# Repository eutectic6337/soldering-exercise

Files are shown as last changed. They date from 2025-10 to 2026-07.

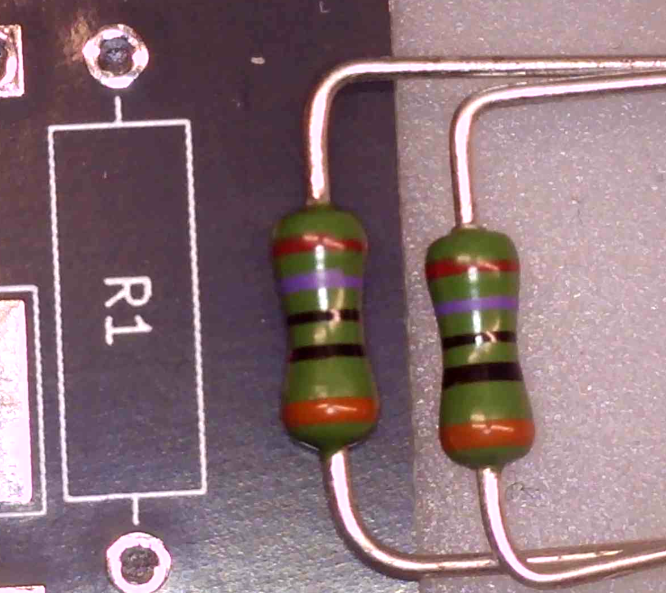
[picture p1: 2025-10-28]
i/THT resistor bend.png

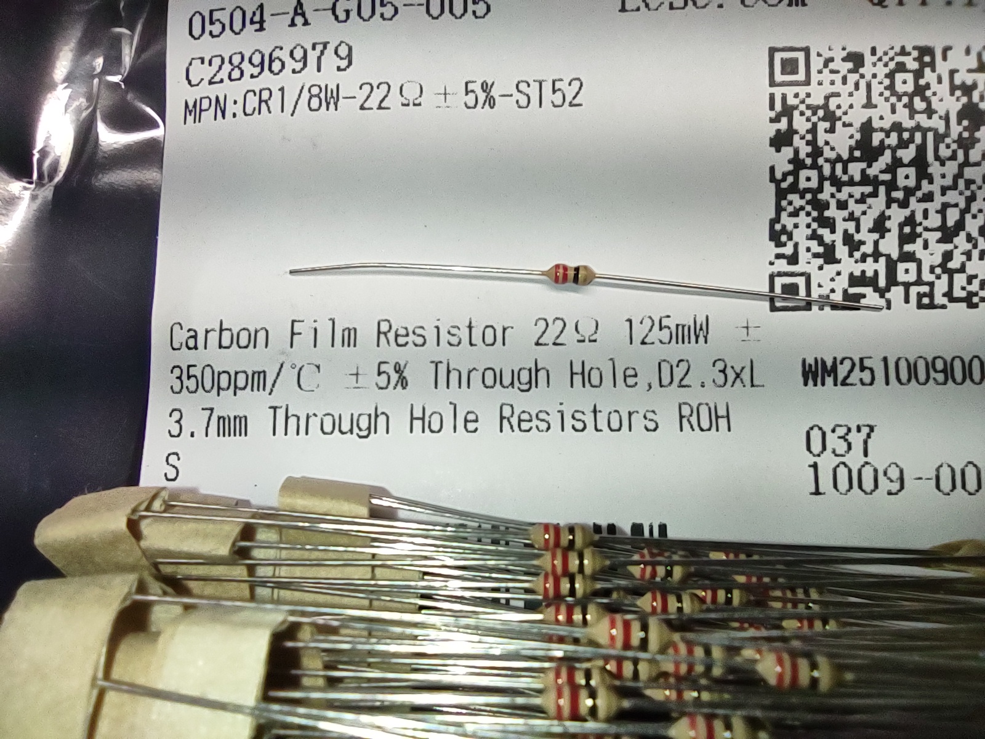
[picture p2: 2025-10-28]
i/THT resistor 22R.jpg

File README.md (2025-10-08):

# soldering-exercise
provide practice for novice solderers with several levels of difficulty

a single board with 2 alternative circuits:

- SAO connector/battery holder, 2 LEDs + 2 resistors

- trickier: SAO connector/battery holder, 555 timer + 2 capacitors + 4 resistors + 2 LEDs

with through-hole and surface-mount pads for each component

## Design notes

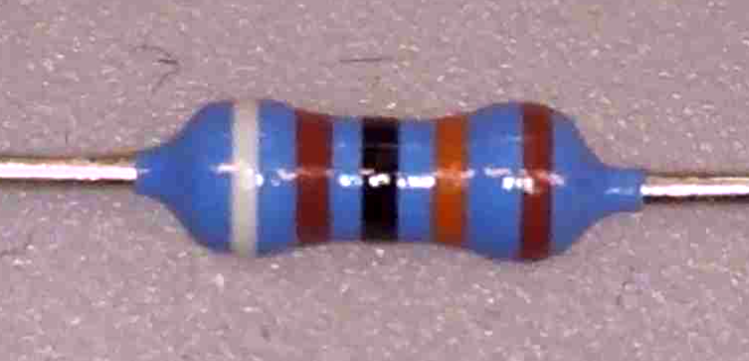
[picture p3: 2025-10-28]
i/THT resistor 910K.png

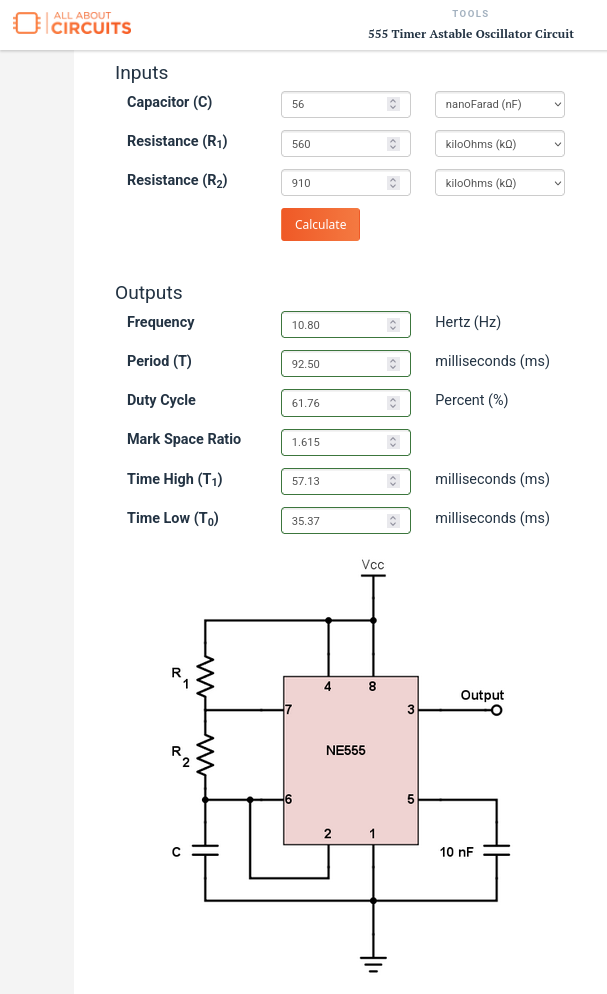
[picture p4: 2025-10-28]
i/Screenshot_555-astable.png

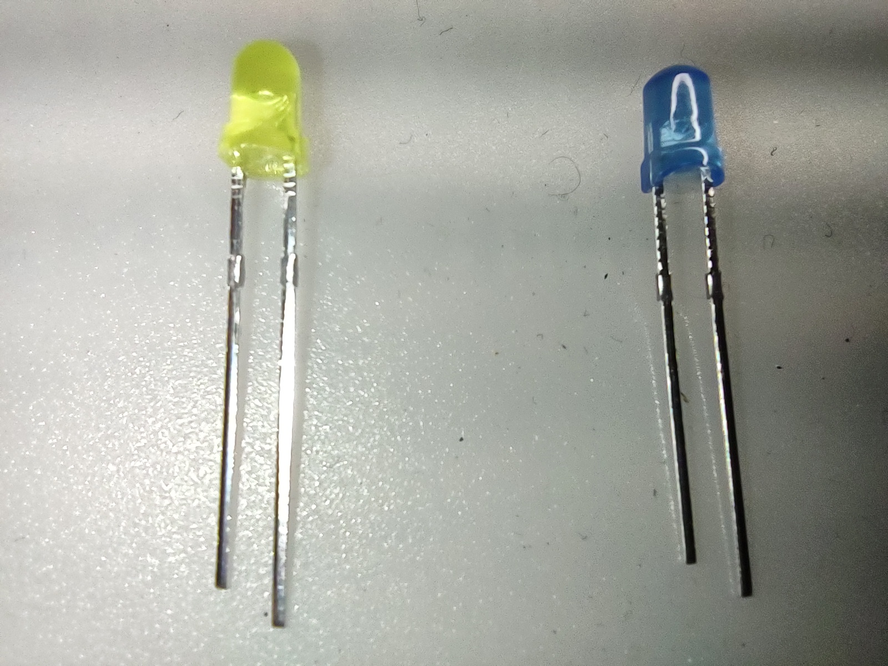
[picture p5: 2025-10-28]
i/THT LED yellow.jpg

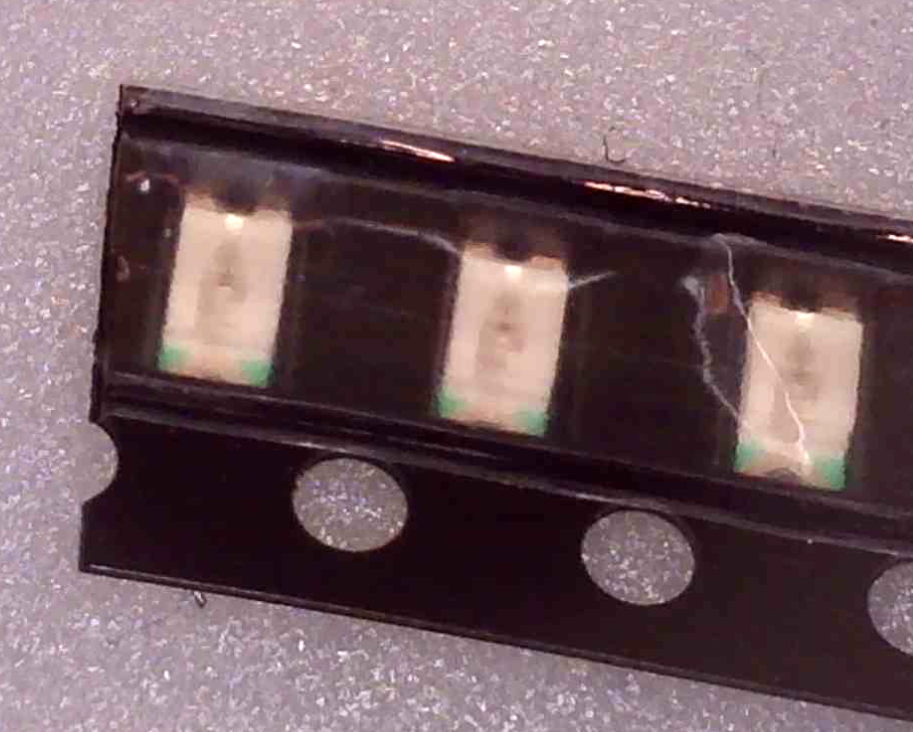
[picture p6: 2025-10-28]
i/SMD LED tape.png

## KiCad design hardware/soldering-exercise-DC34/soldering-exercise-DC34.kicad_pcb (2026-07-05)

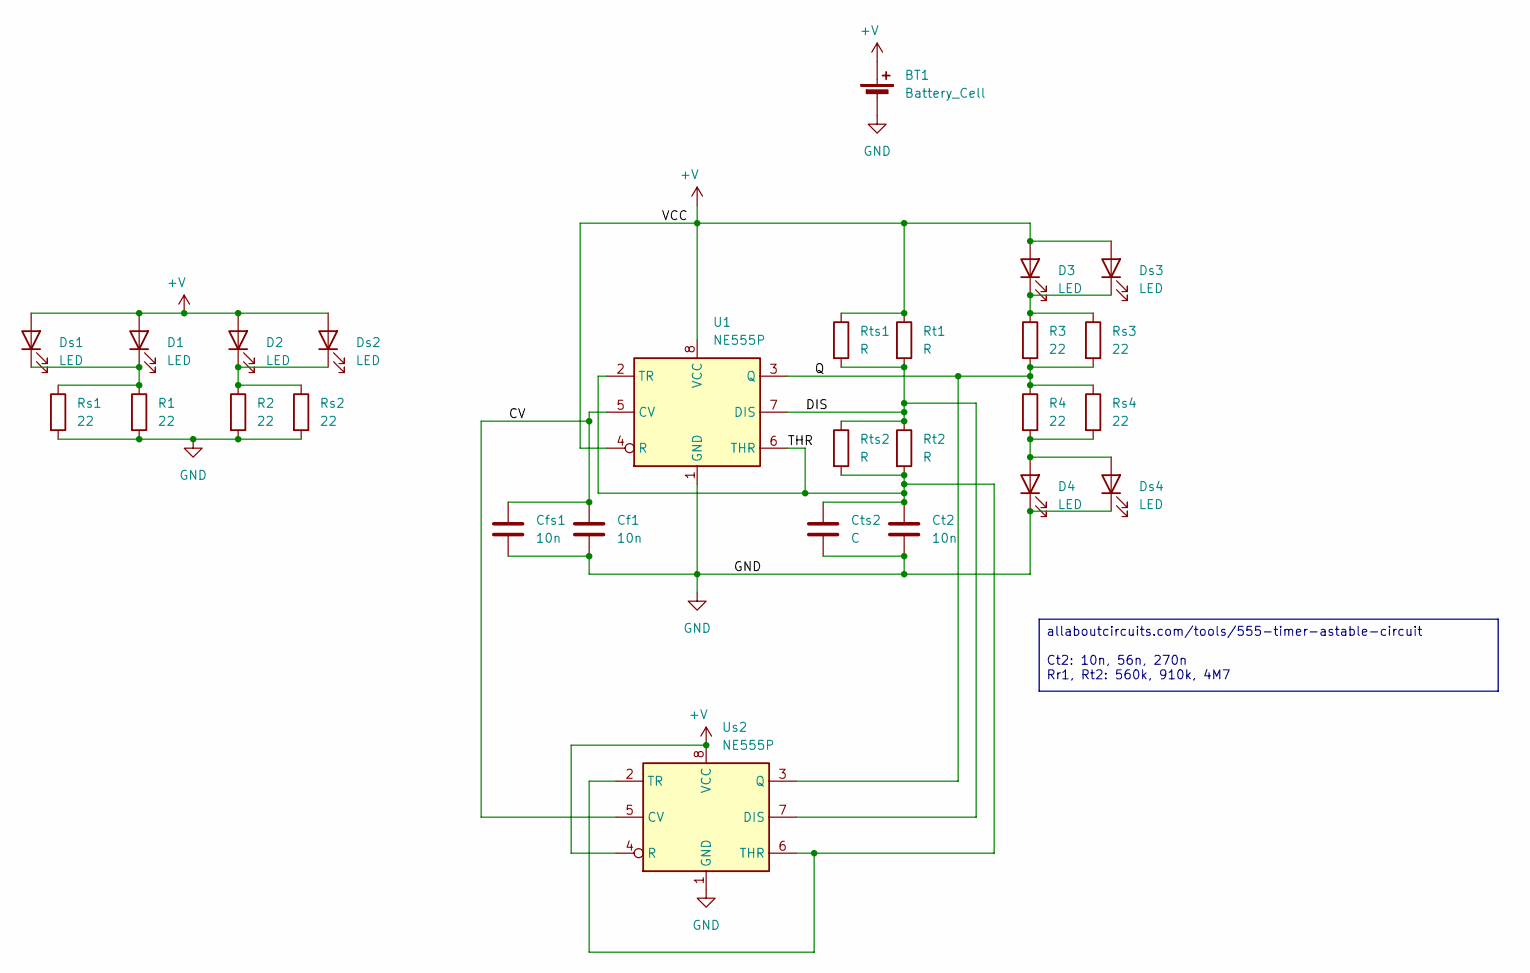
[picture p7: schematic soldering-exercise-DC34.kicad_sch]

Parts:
BT1: Battery_Cell; BatteryHolder_Multicomp_BC-2001_1x2032
Cf1: 10n; C_Rect_L7.0mm_W3.5mm_P5.00mm
Cfs1: 10n; C_1206_3216Metric_Pad1.33x1.80mm_HandSolder
Ct2: 10n; C_Rect_L7.0mm_W3.5mm_P5.00mm
Cts2: C; C_1206_3216Metric_Pad1.33x1.80mm_HandSolder
D1, D2, D3, D4: LED; LED_D5.0mm
Ds1, Ds2, Ds3, Ds4: LED; LED_1206_3216Metric_Pad1.42x1.75mm_HandSolder
R1, R2, R3, R4: 22; R_Axial_DIN0309_L9.0mm_D3.2mm_P12.70mm_Horizontal
Rs1, Rs2, Rs3, Rs4: 22; R_1206_3216Metric_Pad1.30x1.75mm_HandSolder
Rt1, Rt2: R; R_Axial_DIN0309_L9.0mm_D3.2mm_P12.70mm_Horizontal
Rts1, Rts2: R; R_1206_3216Metric_Pad1.30x1.75mm_HandSolder
U1: NE555P; DIP-8_W7.62mm
Us2: NE555P; SOIC-8_3.9x4.9mm_P1.27mm

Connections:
+V: BT1.1 (+), D1.2 (A), D2.2 (A), D3.2 (A), Ds1.2 (A), Ds2.2 (A), Ds3.2 (A), Rt1.1, Rts1.1, U1.4 (R), U1.8 (VCC), Us2.4 (R), Us2.8 (VCC); also elsewhere on the board
/CV: Cf1.1, Cfs1.1, U1.5 (CV), Us2.5 (CV)
/DIS: Rt1.2, Rt2.1, Rts1.2, Rts2.1, U1.7 (DIS), Us2.7 (DIS)
/Q: R3.2, R4.1, Rs3.2, Rs4.1, U1.3 (Q), Us2.3 (Q)
/THR: Ct2.1, Cts2.1, Rt2.2, Rts2.2, U1.2 (TR), U1.6 (THR), Us2.2 (TR), Us2.6 (THR)
GND: BT1.2 (-), Cf1.2, Cfs1.2, Ct2.2, Cts2.2, D4.1 (K), Ds4.1 (K), R1.2, R2.2, Rs1.2, Rs2.2, U1.1 (GND), Us2.1 (GND)
unnamed: D1.1 (K), Ds1.1 (K), R1.1, Rs1.1
unnamed: D2.1 (K), Ds2.1 (K), R2.1, Rs2.1
unnamed: D3.1 (K), Ds3.1 (K), R3.1, Rs3.1
unnamed: D4.2 (A), Ds4.2 (A), R4.2, Rs4.2

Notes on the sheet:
allaboutcircuits.com/tools/555-timer-astable-circuit Ct2: 10n, 56n, 270n Rr1, Rt2: 560k, 910k, 4M7

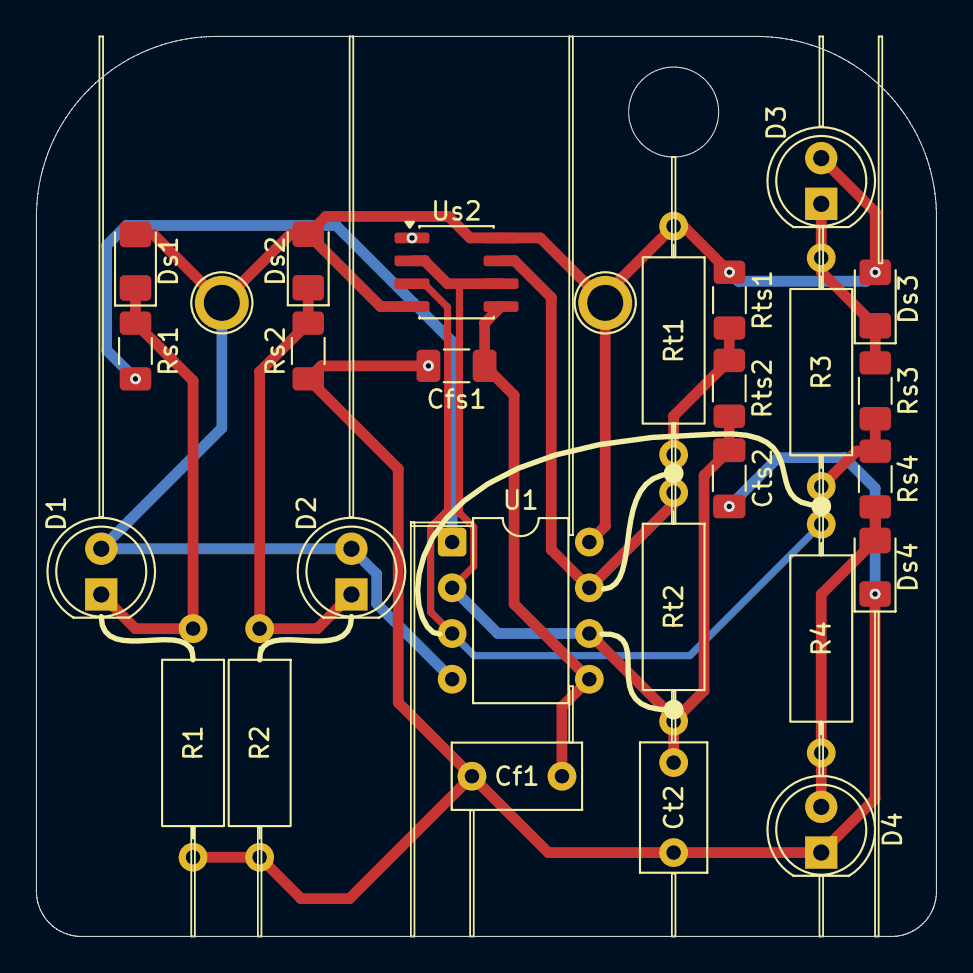
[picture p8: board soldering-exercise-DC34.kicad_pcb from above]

Board: 2 copper layers, 50.0 x 50.0 mm, 30 parts (1 on the bottom side), 10 nets.

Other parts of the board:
V1, V1#2: TestPoint_Plated_Hole_D2.0mm
mount1: MountingHole_5mm

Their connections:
+V: V1.1, V1#2.1; also elsewhere on the board

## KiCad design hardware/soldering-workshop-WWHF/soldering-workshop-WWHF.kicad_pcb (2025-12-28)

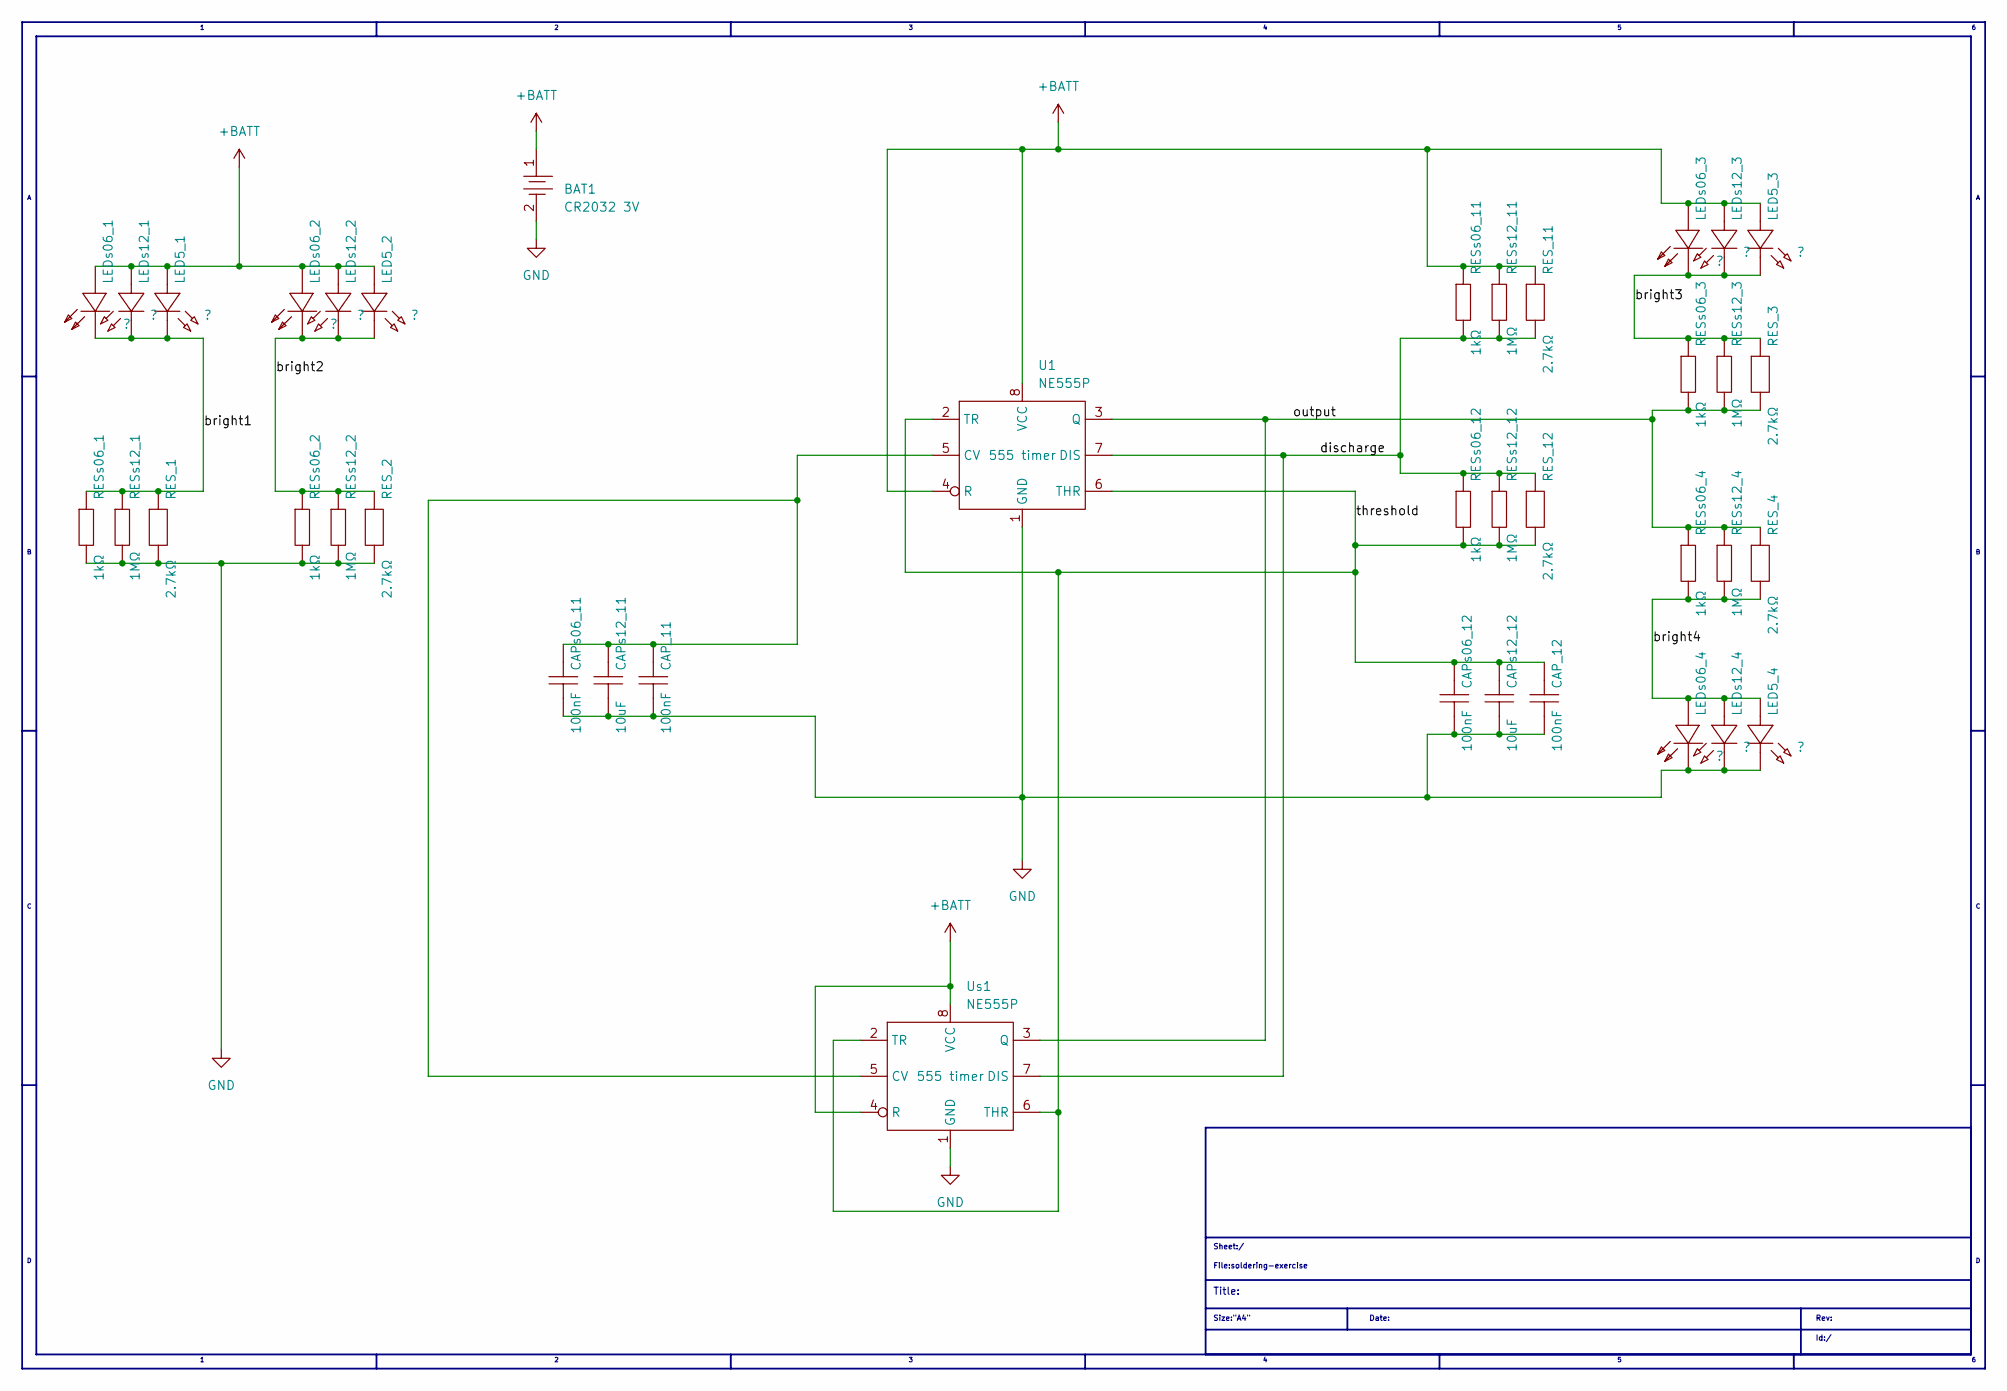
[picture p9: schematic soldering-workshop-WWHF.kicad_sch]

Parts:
BAT1: CR2032 3V; BatteryHolder_Multicomp_BC-2001_1x2032; MANUFACTURER PART CR2032弯脚电池片铜 3V; LCSC PART NAME CR2032弯脚电池片铜 3V
CAP_11, CAP_12: 100nF; C_Rect_L7.0mm_W2.5mm_P5.00mm; TOLERANCE ±10%; VOLTAGE RATING 310V; MANUFACTURER PART MX2104KQ3B30YB20TS1R; LCSC PART NAME 100nF ±10% 310V
CAPs06_11, CAPs06_12: 100nF; C_0603_1608Metric; TOLERANCE ±10%; VOLTAGE RATING 50V; MANUFACTURER PART CC0603KRX7R9BB104; LCSC PART NAME 100nF ±10% 50V
CAPs12_11, CAPs12_12: 10uF; C_1206_3216Metric; TOLERANCE ±10%; VOLTAGE RATING 50V; MANUFACTURER PART HGC1206R5106K500NSPJ; LCSC PART NAME 10uF ±10% 50V
LED5_1, LED5_2, LED5_3, LED5_4: ?; LED_D5.0mm; VOLTAGE - FORWARD(VF) 3.4V; MANUFACTURER PART DY-332SUGD-A3; LCSC PART NAME 5mm圆头有边翠绿色
LEDs06_1, LEDs06_2, LEDs06_3, LEDs06_4: ?; LED_0603_1608Metric; MANUFACTURER PART KT-0603R; LCSC PART NAME 0603 红灯 高亮
LEDs12_1, LEDs12_2, LEDs12_3, LEDs12_4: ?; LED_1206_3216Metric; VOLTAGE - FORWARD(VF) 1.8V~2.4V; MANUFACTURER PART P2-1206RTCS2-0.9T-F; LCSC PART NAME 红灯 反贴
RES_1, RES_2, RES_3, RES_4, RES_11, RES_12: 2.7kΩ; R_Axial_DIN0207_L6.3mm_D2.5mm_P10.16mm_Horizontal; TOLERANCE ±1%; MANUFACTURER PART MF0W4FF2701A50; LCSC PART NAME MF0W4FF2701A50
RESs06_1, RESs06_2, RESs06_3, RESs06_4, RESs06_11, RESs06_12: 1kΩ; R_0603_1608Metric; TOLERANCE ±1%; VOLTAGE-SUPPLY(MAX) 75V; MANUFACTURER PART 0603WAF1001T5E; LCSC PART NAME 1kΩ ±1% 100mW 厚膜电阻
RESs12_1, RESs12_2, RESs12_3, RESs12_4, RESs12_11, RESs12_12: 1MΩ; R_1206_3216Metric; TOLERANCE ±1%; VOLTAGE-SUPPLY(MAX) 200V; MANUFACTURER PART 1206W4F1004T5E; JLCPCB PART CLASS Basic Part
U1: 555 timer; DIP-8_W7.62mm
Us1: 555 timer; SOIC-8_3.9x4.9mm_P1.27mm

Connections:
+BATT: BAT1.1, LED5_1.1 (A), LED5_2.1 (A), LED5_3.1 (A), LEDs06_1.2 (A), LEDs06_2.2 (A), LEDs06_3.2 (A), LEDs12_1.2 (A), LEDs12_2.2 (A), LEDs12_3.2 (A), RES_11.2, RESs06_11.2, RESs12_11.2, U1.4 (R), U1.8 (VCC), Us1.4 (R), Us1.8 (VCC)
/bright1: LED5_1.2 (C), LEDs06_1.1 (K), LEDs12_1.1 (C), RES_1.2, RESs06_1.2, RESs12_1.2
/bright2: LED5_2.2 (C), LEDs06_2.1 (K), LEDs12_2.1 (C), RES_2.2, RESs06_2.2, RESs12_2.2
/bright3: LED5_3.2 (C), LEDs06_3.1 (K), LEDs12_3.1 (C), RES_3.2, RESs06_3.2, RESs12_3.2
/bright4: LED5_4.1 (A), LEDs06_4.2 (A), LEDs12_4.2 (A), RES_4.1, RESs06_4.1, RESs12_4.1
/discharge: RES_11.1, RES_12.2, RESs06_11.1, RESs06_12.2, RESs12_11.1, RESs12_12.2, U1.7 (DIS), Us1.7 (DIS); also elsewhere on the board
/output: RES_3.1, RES_4.2, RESs06_3.1, RESs06_4.2, RESs12_3.1, RESs12_4.2, U1.3 (Q), Us1.3 (Q); also elsewhere on the board
/threshold: CAP_12.2, CAPs06_12.2, CAPs12_12.2, RES_12.1, RESs06_12.1, RESs12_12.1, U1.2 (TR), U1.6 (THR), Us1.2 (TR), Us1.6 (THR); also elsewhere on the board
GND: BAT1.2, CAP_11.1, CAP_12.1, CAPs06_11.1, CAPs06_12.1, CAPs12_11.1, CAPs12_12.1, LED5_4.2 (C), LEDs06_4.1 (K), LEDs12_4.1 (C), RES_1.1, RES_2.1, RESs06_1.1, RESs06_2.1, RESs12_1.1, RESs12_2.1, U1.1 (GND), Us1.1 (GND)
unnamed: CAP_11.2, CAPs06_11.2, CAPs12_11.2, U1.5 (CV), Us1.5 (CV)

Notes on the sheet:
Rev:
Sheet:/
Id:/
Date:
Size:"A4"
Title:
File:soldering-exercise

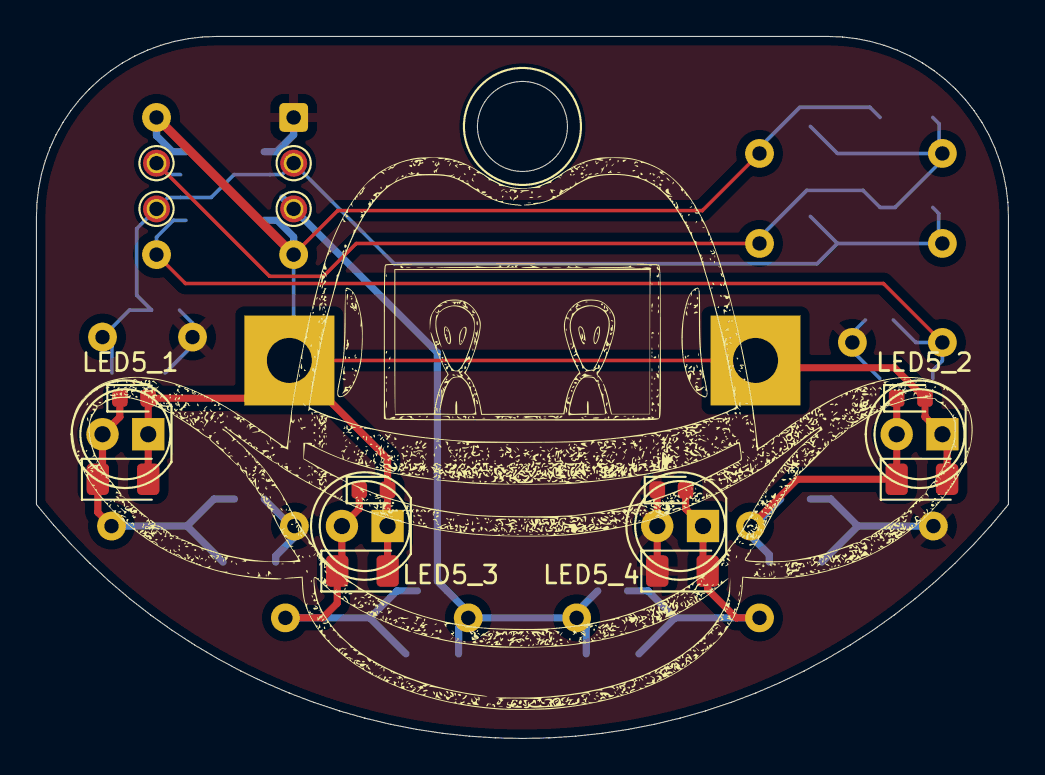
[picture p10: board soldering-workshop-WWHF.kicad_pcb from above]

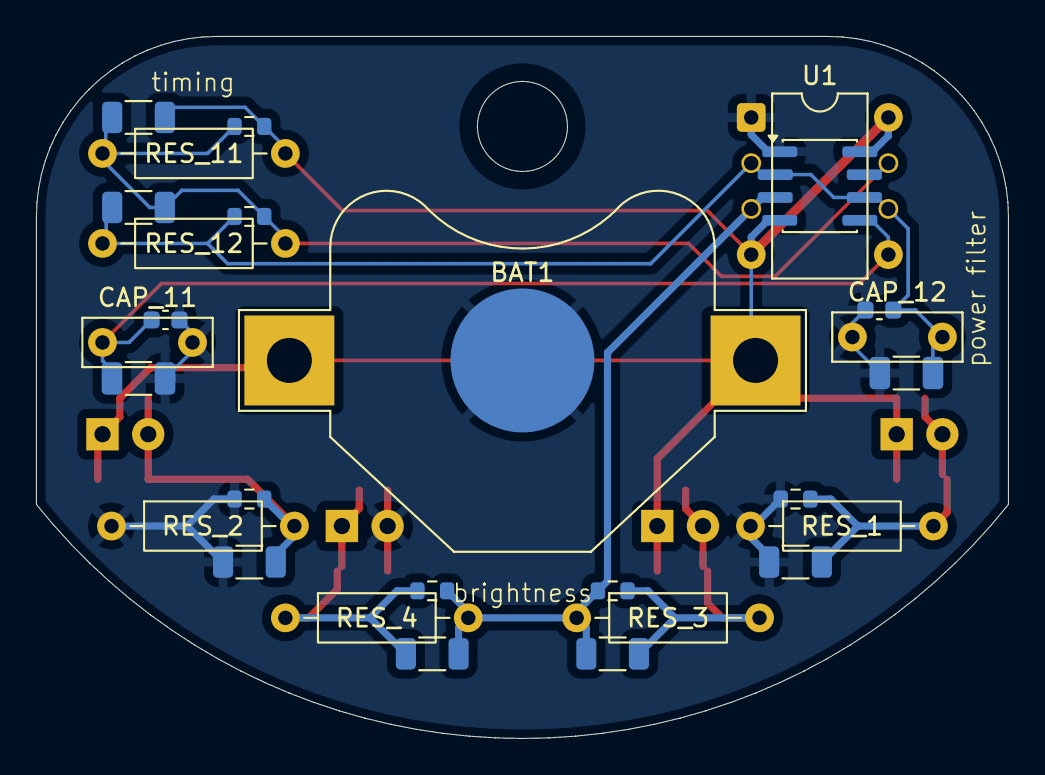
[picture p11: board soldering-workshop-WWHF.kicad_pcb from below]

Board: 2 copper layers, 54.0 x 39.0 mm, 44 parts (27 on the bottom side), 10 nets.

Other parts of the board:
U1p2, U1p3, U1p6, U1p7: TestPoint_Pad_D1.5mm
lanyard: TestPoint_Plated_Hole_D5.0mm

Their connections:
/discharge: U1p7.1; also elsewhere on the board
/output: U1p3.1; also elsewhere on the board
/threshold: U1p2.1, U1p6.1; also elsewhere on the board

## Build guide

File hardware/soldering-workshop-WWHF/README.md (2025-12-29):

# WWHF 2026 soldering exercise

2 different circuits

through-hole, or surface-mount 1206 or 0603

## Simple circuit

2 LEDs light up whenever a battery is inserted

### part selection

2 LEDs of whichever colours you choose, for LED 1 and LED 2

- Red / Green / Yellow	1.8V..2.0V @ 20mA

- Blue / White	2.2V..2.4V @ 20mA

2 brightness-controlling resistors (one for each LED), for RES 1 and RES 2

- (V_battery - V_led) / I_led

    - e.g. (3 - 1.8(red)) / 0.02(bright) = 60 ohm

    - e.g. (3 - 2.4(white)) / 0.005(dim) = 30 ohm

- Recommendation: 30 ohm ... 300 ohm

1 battery holder

## more-complex circuit

555 timer astable multivibrator, alternates between 2 LEDs

### part selection

2 LEDs of whichever colours you choose, for LED 3 and LED 4

2 brightness-controlling resistors (one for each LED), for RES 3 and RES 4

1 555 timer IC

1 power-filtering capacitor, for CAP 12

- any value from 10nF up will be fine

- Recommendation: 10 nF ... 10 uF

1 timing-controlling capacitor, for CAP 11

- any value at all will work

- Recommendation: around 100 nF

2 timing-controlling resistors, for RES 11 and RES 12

- online calculator at https://allaboutcircuits.com/tools/555-timer-astable-circuit

- f = 1.44 / ((R_11 + 2 x R_12) x C_11)

    - T_high = 0.694 x (R_11 + R_12) x C_11

    - T_low = 0.694 x R_12 x C_11

    - e.g. f = 1.44 / ((100 + 2 x 900k) x 200n = 4 Hz, 50% duty

    - e.g. f = 1.44 / ((500k + 2 x 500k) x 100n = 9.6 Hz, 67% duty

- Recommendation: R_11 < 1 k ohm, R_12 > 500 k ohm

- Alternate: make R_11 significantly higher value to make flashing asymmetrical

1 battery holder, if your board does not yet have one

# identifying component values

## surface-mount resistors

Digits as read from the left give the value in ohms,
but the rightmost digit is the number of zeros to put onto the right.

- e.g. 104 = 10 0000 = 100 k ohms

- e.g. 562 = 56 00 = 5.6 k ohms

- e..g 470 = 47 ohms

## through-hole resistors

Colour bands from the left,
converted to digits, give the value in ohms,
but the rightmost band indicates the tolerance
and the second-rightmost band gives the number of zeros to put onto the right.

Ideally, there's a bigger gap between rightmost (tolerance) band and the others, to indicate orientation.
Or, the (left end of the) group of bands is closer to one end of the resistor body than the other.
But sometimes this can be hard to distinguish.
If you can't decide which of the colour bands is the right choice to start reading,
try reading it both ways. One way will give a "nonsense" value and the other way will be correct.

Or, just measure it with a multimeter - the official value will be whatever "preferred value" (see below) is closest to the measured value.

### [preferred values](https://en.wikipedia.org/wiki/E12_series)

Resistor values are only approximate (as indicated by their "tolerance"), and are only manufactured in a limited set of nominal values.
A "nonsense" value is any value that does not appear in that set - you will never find a standard resistor marked with a value outside that set.

| The "E12" series of values |
| --- |
| 1.0, 1.2, 1.5, 1.8, 2.2, 2.7, 3.3, 3.9, 4.7, 5.6, 6.8, 8.2 |

| The "E24" series of values |
| --- |
| 1.0, 1.1, 1.2, 1.3, 1.5, 1.6, 1.8, 2.0, 2.2, 2.4, 2.7, 3.0, 3.3, 3.6, 3.9, 4.3, 4.7, 5.1, 5.6, 6.2, 6.8, 7.5, 8.2, 9.1 |

### [colour code](https://en.wikipedia.org/wiki/Electronic_color_code)

Black = 0

Brown = 1

Red = 2

Orange = 3

Yellow = 4

Green = 5

Blue = 6

Violet or Purple = 7

Grey = 8

White = 9

Gold / Silver / Pink used for tolerance or obscure multiplier only

## examples

- e.g. Brown, Black, Yellow, tolerance... = 10 0000 = 100 k ohms

- e.g. Green, Blue, Red, tolerance... = 56 00 = 5.6 k ohms

- e..g Yello, Violet, Black, tolerance... = 47 ohms

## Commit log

2025-10-08 create schematic
    [soldering-exercise.kicad_pcb, soldering-exercise.kicad_sch]
2025-10-08 add footprints
    [soldering-exercise.kicad_sch]
2025-10-08 start placing components
    [soldering-exercise.kicad_pcb]
2025-10-08 duplicate THT to SMD, layout board
    [soldering-exercise.kicad_pcb, soldering-exercise.kicad_sch]
2025-10-08 document values
    [soldering-exercise.kicad_sch]
2025-10-08 added PhreakNIC logo
    [soldering-exercise.kicad_pcb, soldering-exercise.kicad_sch]
2025-12-28 re-layout for WWHF
    [soldering-workshop-WWHF.kicad_pcb, soldering-workshop-WWHF.kicad_sch]
2025-12-28 done with resistors
2026-07-03 fresh board layout
    [soldering-exercise-DC34.kicad_pcb, soldering-exercise-DC34.kicad_sch]
2026-07-04 add labs logo
    [soldering-exercise-DC34.kicad_pcb]
2026-07-05 tweak artwork
    [soldering-exercise-DC34.kicad_pcb]
